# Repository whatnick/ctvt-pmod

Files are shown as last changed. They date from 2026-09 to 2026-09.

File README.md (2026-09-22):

# CTVT PMOD

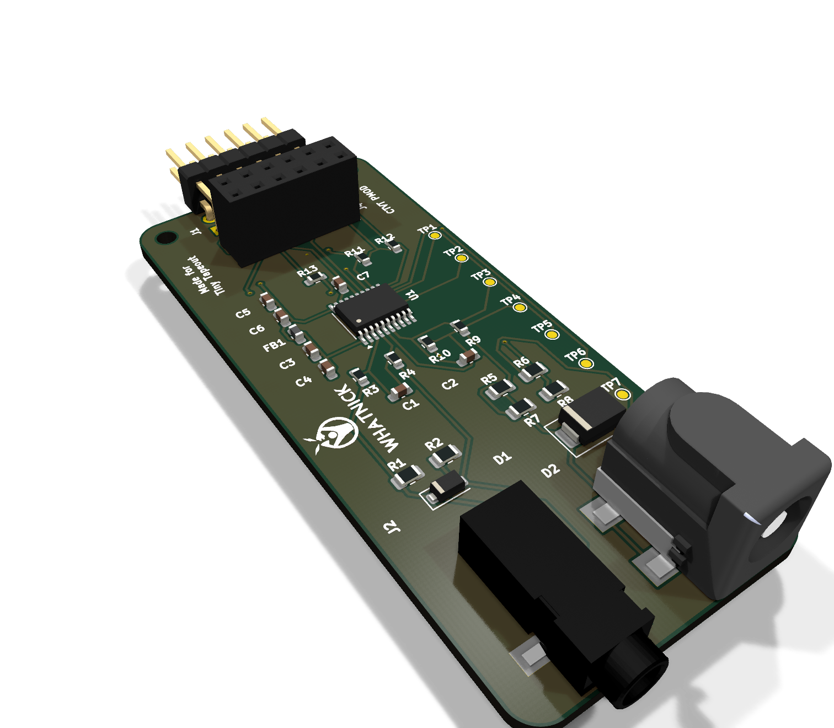
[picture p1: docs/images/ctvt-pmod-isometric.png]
CTVT PMOD assembled isometric render


CTVT PMOD is a compact, open-hardware analog front end for phase-coherent
current and voltage sampling. It uses a TI ADS131M02 dual 24-bit delta-sigma
ADC and is intended for energy-monitoring DSP experiments, including Tiny
Tapeout ASIC projects.

The routed KiCad 10 design is 30 mm x 70 mm with 3 mm corner radii and two
2.2 mm non-plated M2 mounting holes at the PMOD end. The PMOD connectors are
centered together on one short edge; the CT and AC/AC transformer inputs face
away from them at the opposite edge so adjacent PMODs remain usable. All
routed signals use 0.25 mm traces with 0.20 mm copper clearance.

The narrow layout keeps the measurement front end beside other PMODs rather
than blocking them. Both field connectors project beyond the board edge for
comfortable cable access, while the vertical female header provides a second
PMOD connection for stacking or logic-analyzer access.

| Component side | Rear silkscreen and routing |
|---|---|
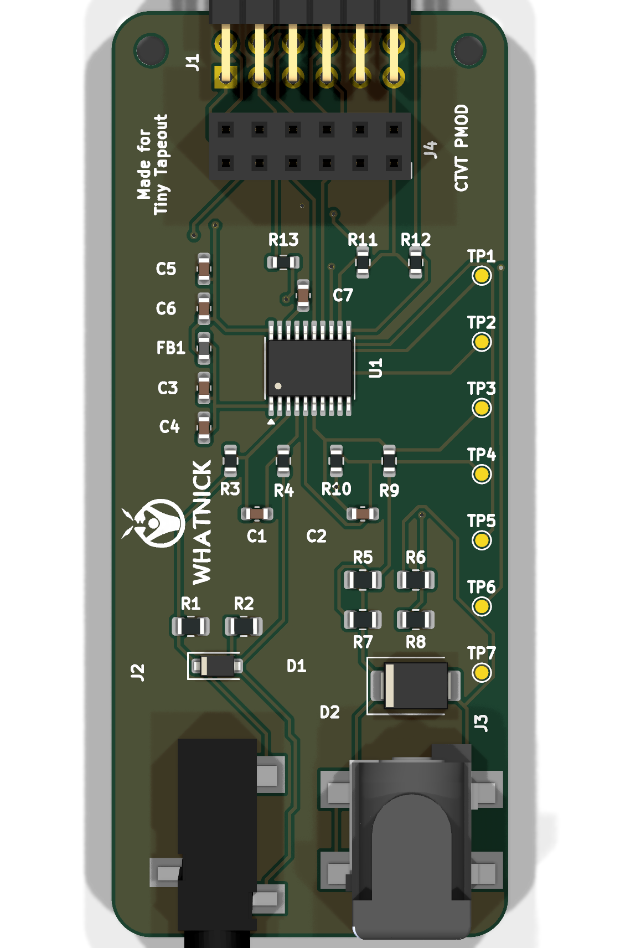
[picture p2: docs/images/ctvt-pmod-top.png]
Component-side render
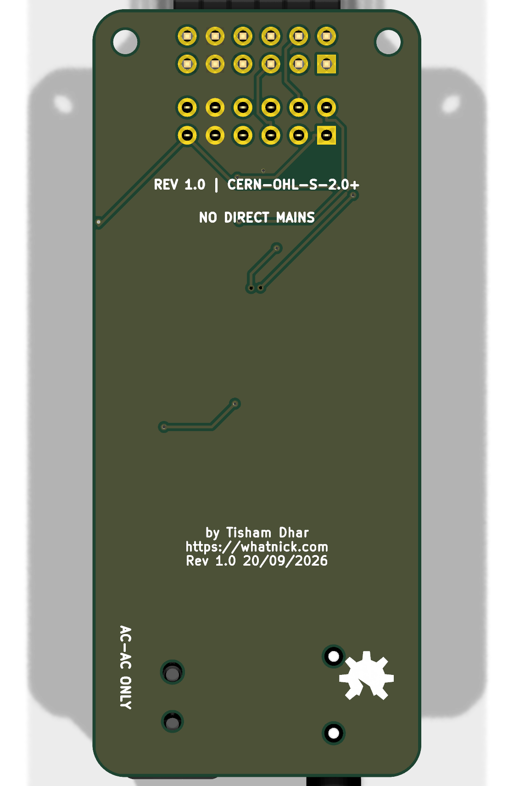
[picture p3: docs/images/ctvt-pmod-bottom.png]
Rear render
|  |  |

## Digital companion

The [CTVT Energy DSP](https://github.com/whatnick/tt-ctvt-energy-dsp)
repository contains the companion Tiny Tapeout design. Its working first stage
captures ADS131M02 frames, performs time-shared multiply-accumulate operations,
and publishes coherent voltage, current, and active-power moments over a host
SPI interface. The roadmap adds calibrated RMS and energy, phase/frequency,
power-quality events, and resource-efficient Goertzel harmonic analysis.

## Signal path

```text
CT jack -> split burden -> protection -> differential RC filter --+
                                                                   |
AC/AC jack -> balanced divider -> protection -> differential RC ---+-> ADS131M02
                                                                        |
3.3 V PMOD <---------------- SPI, DRDY, RESET, CLK ----------------------+
```

- **Current channel:** Same Sky `SJ-3523-SMT-TR` 3.5 mm stereo jack, with
  tip and sleeve as the differential CT input and ring grounded. Two 6.49 ohm
  0.1% burden resistors form a 12.98 ohm differential burden. The jack's
  mating face overhangs the field edge by 2.0 mm so a right-angle plug body
  clears the PCB.
- **Voltage channel:** Same Sky `PJ-002BH-SMT-TR` barrel jack for an isolated
  9-12 VAC transformer. Each leg uses a 100 kohm / 6.49 kohm balanced divider.
- **Filtering:** Each ADC channel has two 1 kohm series resistors and a 10 nF
  C0G differential capacitor, giving an approximate 8 kHz differential pole.
- **Assembly:** All chip passives are 0603 or larger and every fitted
  reference designator is present on silkscreen.
- **Protection:** `SMF3.3CA` on the CT input and `SMBJ18CA` on the transformer
  input.
- **Conversion:** ADS131M02 with filtered analog power, local decoupling,
  seven test points, and simultaneous voltage/current sampling.

## PMOD interface

J1 is the right-angle male peripheral connector. J4 is a vertical female
Wurth `613012243121` pass-through socket; all twelve pins are connected
one-to-one for PMOD chaining.

| Pin | Signal | Direction at CTVT | Purpose |
|---:|---|---|---|
| 1 | CS | Input | SPI chip select |
| 2 | MOSI | Input | SPI data to ADC |
| 3 | MISO | Output | SPI data from ADC |
| 4 | SCLK | Input | SPI clock |
| 5 | GND | Power | Ground |
| 6 | +3V3 | Power | Regulated 3.3 V input |
| 7 | DRDY | Output | Conversion-ready interrupt |
| 8 | RESET | Input | ADC reset |
| 9 | CLK_HOST | Input | Optional external ADC clock |
| 10 | RESERVED | Pass-through | Reserved chained signal |
| 11 | GND | Power | Ground |
| 12 | +3V3 | Power | Regulated 3.3 V input |

## Scaling and calibration

The CT channel differential voltage is:

```text
V_CT_RMS = I_secondary_RMS x 12.98 ohm
```

For example, a 100 A : 50 mA CT produces approximately 0.649 Vrms at rated
primary current. Confirm the selected CT's maximum secondary current and
fault behavior before connection.

The voltage channel nominal divider ratio is:

```text
6.49 kohm / (100 kohm + 6.49 kohm) = 0.06095
```

A 9-12 Vrms isolated transformer therefore produces approximately
0.549-0.731 Vrms differential at the ADC input. Configure the ADS131M02 gain
for the resulting peak voltage and retain headroom for transformer regulation
and mains excursions.

Calibrate voltage gain, current gain, phase, and channel offset against a
traceable low-voltage source before calculating power. TP1-TP4 expose the four
ADC inputs; TP5 is DRDY, TP6 is +3V3, and TP7 is GND.

## Safety

**Use only an isolated CT and a certified isolated AC/AC transformer. Never
connect mains directly to this board.** The barrel jack is an isolated
low-voltage AC input, not a DC supply input. Enclosure, wiring, fusing,
creepage, clearance, and regulatory compliance remain the responsibility of
the final system.

## Build and outputs

Open `ctvt-pmod.kicad_pro` in KiCad 10. The committed schematic and PCB are
complete and routed. Project-local connector footprints and STEP models avoid
dependencies on the ATM90E26 FeatherWing repository.

The design sources are generated in this order:

```powershell
python scripts\generate_schematic.py
& "C:\Program Files\KiCad\10.0\bin\python.exe" scripts\generate_board.py
# Export a Specctra DSN, route it, and save the result as routing\ctvt-pmod.ses.
& "C:\Program Files\KiCad\10.0\bin\python.exe" scripts\finalize_route.py
```

`scripts/finalize_route.py` imports the saved Freerouting session, normalizes
all traces to at least 0.25 mm, verifies the stereo jack's generated 2.0 mm
mating-face overhang, adds the rear OSHW/Whatnick branding, and fills GND zones
on both copper layers. Run `scripts\adjust_stereo_jack.py` to verify the
overhang independently or
`scripts\add_branding.py` to reapply only the branding.
Run `scripts\add_mechanical_features.py` to reapply the 3 mm corner radii and
two M2 mounting holes without disturbing routed copper or manual silkscreen.
Manufacturing exports are generated into ignored `gerbers/` and `bom/`
directories. The reviewed orderable BOM and DigiKey sourcing notes are
committed in [`docs/ctvt-pmod-sourced-bom.csv`](docs/ctvt-pmod-sourced-bom.csv)
and [`docs/bom-sourcing.md`](docs/bom-sourcing.md).

## Repository contents

- `ctvt-pmod.kicad_sch` - complete schematic
- `ctvt-pmod.kicad_pcb` - routed two-layer PCB
- `ctvt-pmod.pretty/` - project-local barrel-jack and PMOD socket footprints
- `models/step/` - project-local connector STEP models
- `routing/ctvt-pmod.ses` - saved autorouter result
- `scripts/` - deterministic schematic, placement, and routing finalization

Licensed under CERN-OHL-S-2.0-or-later.

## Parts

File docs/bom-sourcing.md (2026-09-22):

# DigiKey BOM sourcing

The orderable BOM is in
[`ctvt-pmod-sourced-bom.csv`](ctvt-pmod-sourced-bom.csv). DigiKey parts were
checked through the Product Search API on 2026-09-22 using the Australian
locale, with in-stock and RoHS-compliant filters.

The selected parts preserve the schematic values and PCB footprints. In
particular, the 10 nF C0G capacitors use 0603 `GRM188` parts and the ferrite
bead uses a 0603 `MPZ1608` part; the earlier `GRM155` and `BLM15` MPNs were
0402 parts and did not match the board footprints.

R1 and R2 use TE Connectivity Holsworthy `RN73C2A6R49BTDF`, sourced from
[Mouser Australia](https://au.mouser.com/en/ProductDetail/TE-Connectivity-Holsworthy/RN73C2A6R49BTDF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).
It is a footprint-compatible 6.49 ohm, 0.1%, 0805 thin-film resistor with a
10 ppm/degree C temperature coefficient and a 0.1 W rating.

Stock and pricing change continuously. Recheck all DigiKey part numbers before
ordering, especially the ADC, connectors, D1, C7, and the precision resistors.

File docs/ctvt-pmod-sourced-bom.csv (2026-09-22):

References | Quantity | Value | Manufacturer | Manufacturer Part Number | Supplier | Supplier Part Number | Package | Sourcing Note
C1 C2 | 2 | 10nF C0G | Murata Electronics | GRM1885C1H103JA01D | DigiKey | 490-9666-1-ND | 0603 | 50 V C0G 5%
C3 C5 | 2 | 1uF | KEMET | C0603C105K4RACTU | DigiKey | 399-C0603C105K4RACTUCT-ND | 0603 | 16 V X7R 10%
C4 C6 | 2 | 100nF | KEMET | C0603C104K5RACTU | DigiKey | 399-C0603C104K5RACTUCT-ND | 0603 | 50 V X7R 10%
C7 | 1 | 220nF | KEMET | C0603C224K4RACTU | DigiKey | 399-C0603C224K4RACTUCT-ND | 0603 | 16 V X7R 10%
D1 | 1 | SMF3.3CA | Good-Ark Semiconductor | GSMF3.3CA | DigiKey | 4786-GSMF3.3CACT-ND | SOD-123F | 3.3 V bidirectional TVS
D2 | 1 | SMBJ18CA | Littelfuse | SMBJ18CA | DigiKey | SMBJ18CALFCT-ND | DO-214AA SMB | 18 V bidirectional TVS
FB1 | 1 | 600R@100MHz | TDK | MPZ1608S601ATA00 | DigiKey | 445-MPZ1608S601ATA00CT-ND | 0603 | 600 ohm at 100 MHz
J1 | 1 | Tiny Tapeout PMOD | Samtec | TSW-106-08-G-D-RA | DigiKey | 612-TSW-106-08-G-D-RA-ND | 2x6 2.54 mm THT | Right-angle male header
J2 | 1 | SJ-3523-SMT-TR | Same Sky | SJ-3523-SMT-TR | DigiKey | CP-3523SJCT-ND | SMD | 3.5 mm stereo jack
J3 | 1 | PJ-002BH-SMT-TR | Same Sky | PJ-002BH-SMT-TR | DigiKey | CP-002BHPJCT-ND | SMD | 2.5 x 5.5 mm barrel jack
J4 | 1 | 613012243121 | Wurth Elektronik | 613012243121 | DigiKey | 732-613012243121-ND | 2x6 2.54 mm THT | Vertical female socket
R1 R2 | 2 | 6.49R 0.1% | TE Connectivity Holsworthy | RN73C2A6R49BTDF | Mouser | RN73C2A6R49BTDF | 0805 | 10 ppm/C thin film
R3 R4 R9 R10 | 4 | 1k 0.1% | Susumu | RG1608P-102-B-T5 | DigiKey | RG16P1.0KBCT-ND | 0603 | 25 ppm/C thin film
R5 R6 | 2 | 100k 0.1% | Panasonic Industry | ERA-6AEB104V | DigiKey | P100KDACT-ND | 0805 | 25 ppm/C thin film
R7 R8 | 2 | 6.49k 0.1% | Yageo | RT0805BRD076K49L | DigiKey | YAG1965CT-ND | 0805 | 25 ppm/C thin film
R11 R12 | 2 | 10k 1% | Stackpole Electronics | RMCF0603FT10K0 | DigiKey | RMCF0603FT10K0CT-ND | 0603 | General-purpose
R13 | 1 | 33R 1% | Yageo | RC0603FR-0733RL | DigiKey | 13-RC0603FR-0733RLCT-ND | 0603 | General-purpose
U1 | 1 | ADS131M02IPWR | Texas Instruments | ADS131M02IPWR | DigiKey | 296-ADS131M02IPWRCT-ND | TSSOP-20 | 24-bit dual-channel ADC

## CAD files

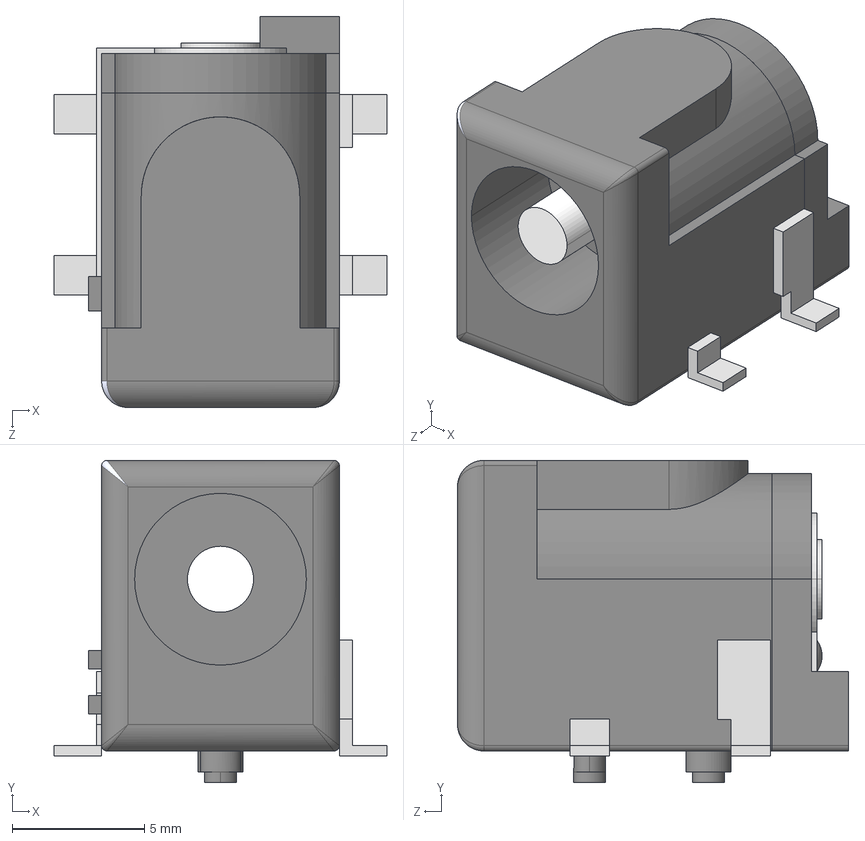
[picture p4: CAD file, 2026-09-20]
models/step/CUI_PJ-002BH-SMT-TR.step
12.6 x 12.2 x 14.8 mm

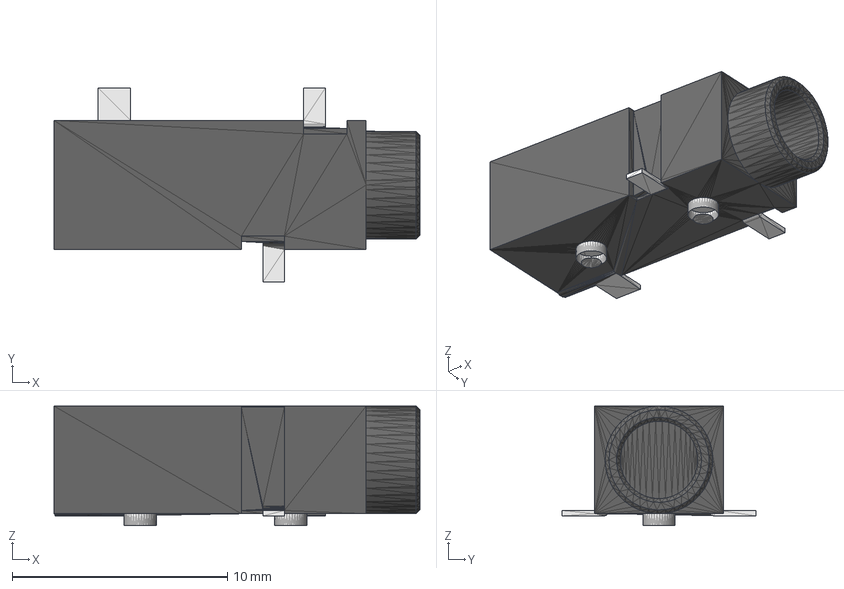
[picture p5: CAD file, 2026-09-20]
models/step/CUI_SJ-3523.step
17.0 x 9.00 x 5.80 mm

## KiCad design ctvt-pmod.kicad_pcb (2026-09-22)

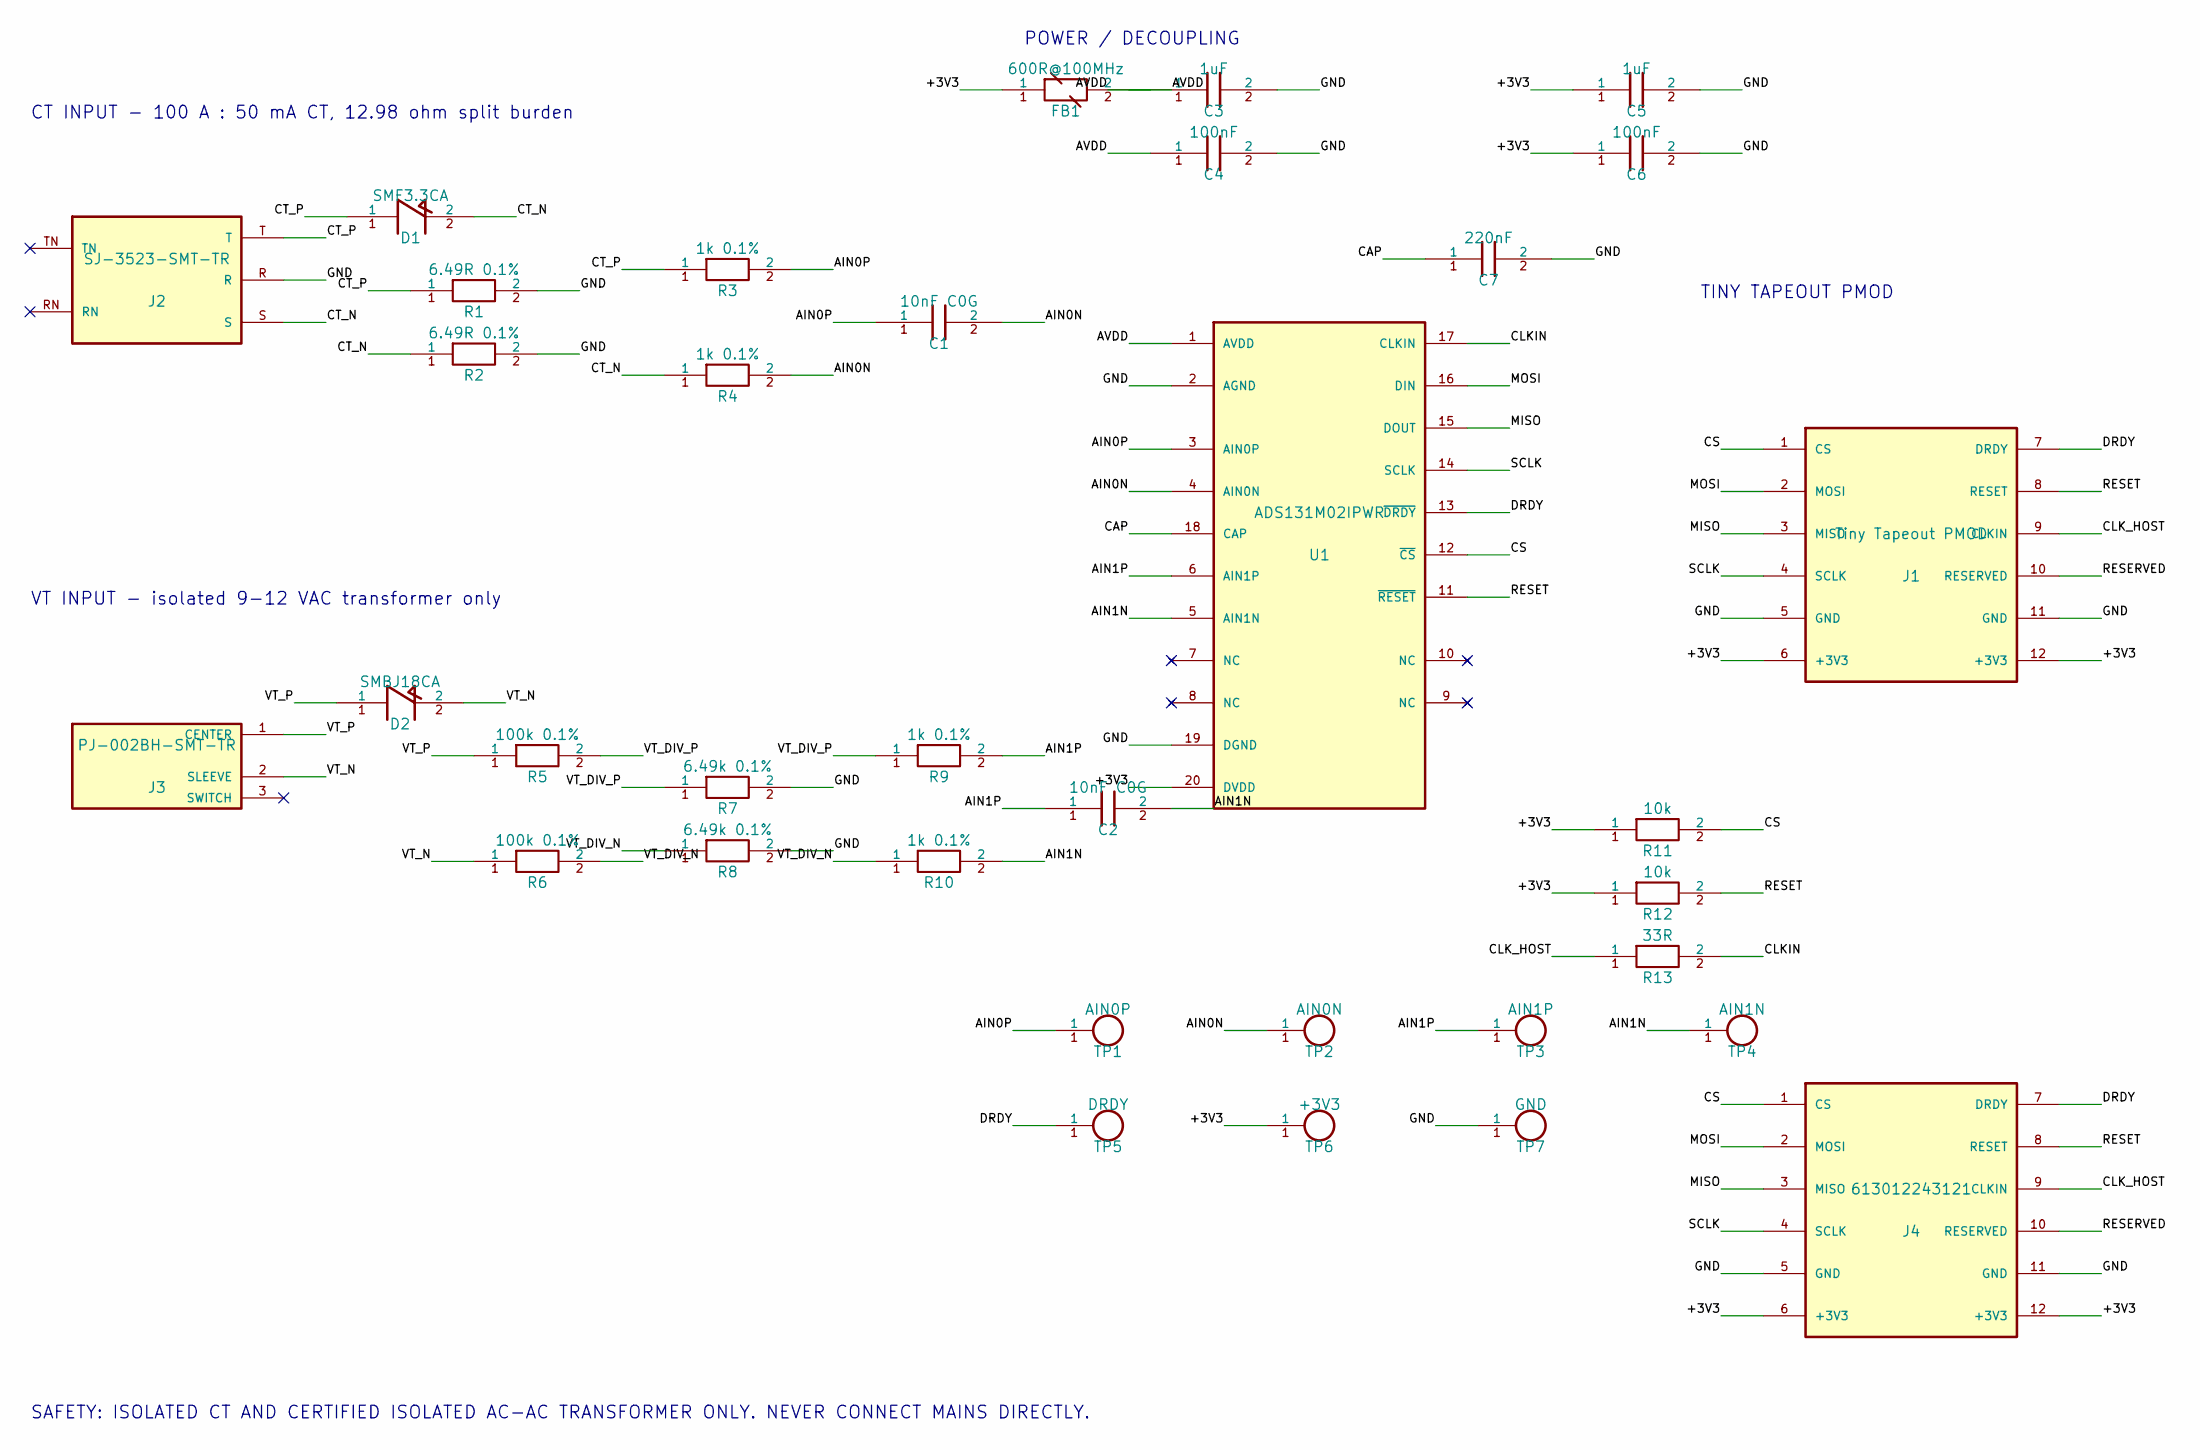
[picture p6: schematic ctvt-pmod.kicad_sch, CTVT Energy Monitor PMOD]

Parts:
C1, C2: 10nF C0G; C_0603_1608Metric; MPN GRM1555C1H103JA01D
C3, C5: 1uF; C_0603_1608Metric
C4, C6: 100nF; C_0603_1608Metric
C7: 220nF; C_0603_1608Metric
D1: SMF3.3CA; D_SOD-123F
D2: SMBJ18CA; D_SMB
FB1: 600R@100MHz; L_0603_1608Metric; MPN BLM15AG601SN1D
J1: Tiny Tapeout PMOD; PinHeader_2x06_P2.54mm_Horizontal
J2: SJ-3523-SMT-TR; Jack_3.5mm_CUI_SJ-3523-SMT_Horizontal; MPN SJ-3523-SMT-TR
J3: PJ-002BH-SMT-TR; DC_BARREL_JACK_SMD_2MM; MPN PJ-002BH-SMT-TR
J4: 613012243121; PinSocket_2x06_P2.54mm_PMODHost1A; MPN 613012243121
R1, R2: 6.49R 0.1%; R_0805_2012Metric; MPN TNPW08056R49BEEA
R3, R4, R9, R10: 1k 0.1%; R_0603_1608Metric
R5, R6: 100k 0.1%; R_0805_2012Metric
R7, R8: 6.49k 0.1%; R_0805_2012Metric
R11, R12: 10k; R_0603_1608Metric
R13: 33R; R_0603_1608Metric
TP1: AIN0P; TestPoint_Pad_D1.0mm
TP2: AIN0N; TestPoint_Pad_D1.0mm
TP3: AIN1P; TestPoint_Pad_D1.0mm
TP4: AIN1N; TestPoint_Pad_D1.0mm
TP5: DRDY; TestPoint_Pad_D1.0mm
TP6: +3V3; TestPoint_Pad_D1.0mm
TP7: GND; TestPoint_Pad_D1.0mm
U1: ADS131M02IPWR; TSSOP-20_4.4x6.5mm_P0.65mm; MPN ADS131M02IPWR

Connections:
+3V3: C5.1, C6.1, FB1.1, J1.6 (+3V3), J1.12 (+3V3), J4.6 (+3V3), J4.12 (+3V3), R11.1, R12.1, TP6.1, U1.20 (DVDD)
AIN0N: C1.2, R4.2, TP2.1, U1.4 (AIN0N)
AIN0P: C1.1, R3.2, TP1.1, U1.3 (AIN0P)
AIN1N: C2.2, R10.2, TP4.1, U1.5 (AIN1N)
AIN1P: C2.1, R9.2, TP3.1, U1.6 (AIN1P)
AVDD: C3.1, C4.1, FB1.2, U1.1 (AVDD)
CAP: C7.1, U1.18 (CAP)
CLKIN: R13.2, U1.17 (CLKIN)
CLK_HOST: J1.9 (CLKIN), J4.9 (CLKIN), R13.1
CS: J1.1 (CS), J4.1 (CS), R11.2, U1.12 (~CS)
CT_N: D1.2, J2.S, R2.1, R4.1
CT_P: D1.1, J2.T, R1.1, R3.1
DRDY: J1.7 (DRDY), J4.7 (DRDY), TP5.1, U1.13 (~DRDY)
GND: C3.2, C4.2, C5.2, C6.2, C7.2, J1.5 (GND), J1.11 (GND), J2.R, J4.5 (GND), J4.11 (GND), R1.2, R2.2, R7.2, R8.2, TP7.1, U1.2 (AGND), U1.19 (DGND)
MISO: J1.3 (MISO), J4.3 (MISO), U1.15 (DOUT)
MOSI: J1.2 (MOSI), J4.2 (MOSI), U1.16 (DIN)
RESERVED: J1.10 (RESERVED), J4.10 (RESERVED)
RESET: J1.8 (RESET), J4.8 (RESET), R12.2, U1.11 (~RESET)
SCLK: J1.4 (SCLK), J4.4 (SCLK), U1.14 (SCLK)
VT_DIV_N: R6.2, R8.1, R10.1
VT_DIV_P: R5.2, R7.1, R9.1
VT_N: D2.2, J3.2 (SLEEVE), R6.1
VT_P: D2.1, J3.1 (CENTER), R5.1

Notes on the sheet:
CT INPUT - 100 A : 50 mA CT, 12.98 ohm split burden
VT INPUT - isolated 9-12 VAC transformer only
POWER / DECOUPLING
TINY TAPEOUT PMOD
SAFETY: ISOLATED CT AND CERTIFIED ISOLATED AC-AC TRANSFORMER ONLY. NEVER CONNECT MAINS DIRECTLY.

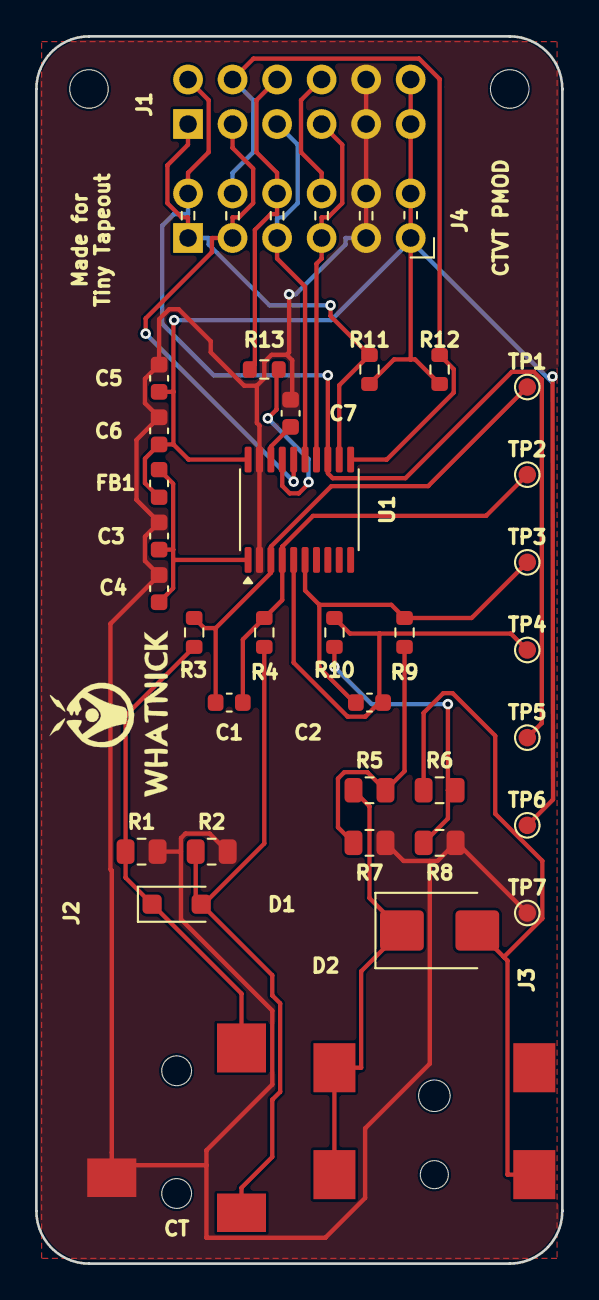
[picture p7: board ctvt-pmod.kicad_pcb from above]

Board: 2 copper layers, 30.0 x 70.0 mm, 39 parts (1 on the bottom side), 23 nets.

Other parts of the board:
H1, H2: M2 mounting hole; MountingHole_2.2mm_M2
LOGO1: OSHW-LOGO-M
LOGO2: Whatnick_logo

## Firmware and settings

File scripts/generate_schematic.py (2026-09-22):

from __future__ import annotations

import shutil
import subprocess
import tempfile
from dataclasses import dataclass, field
from pathlib import Path


ROOT = Path(__file__).resolve().parents[1]
OUTPUT = ROOT / "ctvt-pmod.kicad_sch"
SYMBOL_LIBRARY_OUTPUT = ROOT / "ctvt-pmod-cache.kicad_sym"
SYMBOL_TABLE_OUTPUT = ROOT / "sym-lib-table"
KICAD_CLI = Path(r"C:\Program Files\KiCad\10.0\bin\kicad-cli.exe")
KICAD_REVIVE = (
    "git+https://github.com/mgyenik/kicad-revive.git"
    "@2847877af4a3114fd1e61ab2f660089fa3c27ecc"
)


CUSTOM_LIBRARY = r"""EESchema-LIBRARY Version 2.4
#encoding utf-8
#
# ADS131M02PW
#
DEF ADS131M02PW U 0 40 Y Y 1 F N
F0 "U" 0 1150 50 H V C CNN
F1 "ADS131M02PW" 0 1050 50 H V C CNN
F2 "" 0 0 50 H I C CNN
F3 "" 0 0 50 H I C CNN
DRAW
S -500 1000 500 -1300 0 1 12 f
X AVDD 1 -700 900 200 R 40 40 1 1 W
X ~RESET 11 700 -300 200 L 40 40 1 1 I
X ~CS 12 700 -100 200 L 40 40 1 1 I
X ~DRDY 13 700 100 200 L 40 40 1 1 O
X SCLK 14 700 300 200 L 40 40 1 1 I
X DOUT 15 700 500 200 L 40 40 1 1 O
X DIN 16 700 700 200 L 40 40 1 1 I
X CLKIN 17 700 900 200 L 40 40 1 1 I
X CAP 18 -700 0 200 R 40 40 1 1 w
X DGND 19 -700 -1000 200 R 40 40 1 1 W
X AGND 2 -700 700 200 R 40 40 1 1 W
X DVDD 20 -700 -1200 200 R 40 40 1 1 W
X AIN0P 3 -700 400 200 R 40 40 1 1 I
X AIN0N 4 -700 200 200 R 40 40 1 1 I
X AIN1N 5 -700 -400 200 R 40 40 1 1 I
X AIN1P 6 -700 -200 200 R 40 40 1 1 I
X NC 7 -700 -600 200 R 40 40 1 1 N
X NC 8 -700 -800 200 R 40 40 1 1 N
X NC 9 700 -800 200 L 40 40 1 1 N
X NC 10 700 -600 200 L 40 40 1 1 N
ENDDRAW
ENDDEF
#
# R
#
DEF R R 0 0 Y Y 1 F N
F0 "R" 0 80 50 H V C CNN
F1 "R" 0 0 50 H V C CNN
F2 "" 0 0 50 H I C CNN
F3 "" 0 0 50 H I C CNN
DRAW
S -100 50 100 -50 0 1 10 N
X 1 1 -300 0 200 R 40 40 1 1 P
X 2 2 300 0 200 L 40 40 1 1 P
ENDDRAW
ENDDEF
#
# C
#
DEF C C 0 0 Y Y 1 F N
F0 "C" 0 90 50 H V C CNN
F1 "C" 0 -90 50 H V C CNN
F2 "" 0 0 50 H I C CNN
F3 "" 0 0 50 H I C CNN
DRAW
P 2 0 1 12 -30 80 -30 -80 N
P 2 0 1 12 30 80 30 -80 N
X 1 1 -300 0 270 R 40 40 1 1 P
X 2 2 300 0 270 L 40 40 1 1 P
ENDDRAW
ENDDEF
#
# FB
#
DEF FB FB 0 0 Y Y 1 F N
F0 "FB" 0 90 50 H V C CNN
F1 "Ferrite" 0 -90 50 H V C CNN
F2 "" 0 0 50 H I C CNN
F3 "" 0 0 50 H I C CNN
DRAW
S -100 50 100 -50 0 1 10 N
P 2 0 1 10 -70 80 -20 30 N
P 2 0 1 10 20 -30 70 -80 N
X 1 1 -300 0 200 R 40 40 1 1 P
X 2 2 300 0 200 L 40 40 1 1 w
ENDDRAW
ENDDEF
#
# TVS
#
DEF TVS D 0 0 Y Y 1 F N
F0 "D" 0 100 50 H V C CNN
F1 "TVS" 0 -100 50 H V C CNN
F2 "" 0 0 50 H I C CNN
F3 "" 0 0 50 H I C CNN
DRAW
P 3 0 1 12 -60 -80 -60 80 70 0 N
P 4 0 1 12 70 -80 70 80 40 50 100 20 N
X 1 1 -300 0 240 R 40 40 1 1 P
X 2 2 300 0 230 L 40 40 1 1 P
ENDDRAW
ENDDEF
#
# AUDIO_JACK
#
DEF AUDIO_JACK J 0 40 Y Y 1 F N
F0 "J" 0 450 50 H V C CNN
F1 "CT stereo jack" 0 350 50 H V C CNN
F2 "" 0 0 50 H I C CNN
F3 "" 0 0 50 H I C CNN
DRAW
S -400 300 400 -300 0 1 12 f
X T T 600 200 200 L 40 40 1 1 P
X R R 600 0 200 L 40 40 1 1 P
X S S 600 -200 200 L 40 40 1 1 P
X TN TN -600 150 200 R 40 40 1 1 P
X RN RN -600 -150 200 R 40 40 1 1 P
ENDDRAW
ENDDEF
#
# BARREL_JACK
#
DEF BARREL_JACK J 0 40 Y Y 1 F N
F0 "J" 0 350 50 H V C CNN
F1 "AC-AC barrel jack" 0 250 50 H V C CNN
F2 "" 0 0 50 H I C CNN
F3 "" 0 0 50 H I C CNN
DRAW
S -400 200 400 -200 0 1 12 f
X CENTER 1 600 150 200 L 40 40 1 1 P
X SLEEVE 2 600 -50 200 L 40 40 1 1 P
X SWITCH 3 600 -150 200 L 40 40 1 1 P
ENDDRAW
ENDDEF
#
# PMOD
#
DEF PMOD J 0 40 Y Y 1 F N
F0 "J" 0 750 50 H V C CNN
F1 "Tiny Tapeout PMOD" 0 650 50 H V C CNN
F2 "" 0 0 50 H I C CNN
F3 "" 0 0 50 H I C CNN
DRAW
S -500 600 500 -600 0 1 12 f
X CS 1 -700 500 200 R 40 40 1 1 B
X MOSI 2 -700 300 200 R 40 40 1 1 B
X MISO 3 -700 100 200 R 40 40 1 1 B
X SCLK 4 -700 -100 200 R 40 40 1 1 B
X GND 5 -700 -300 200 R 40 40 1 1 w
X +3V3 6 -700 -500 200 R 40 40 1 1 w
X DRDY 7 700 500 200 L 40 40 1 1 B
X RESET 8 700 300 200 L 40 40 1 1 B
X CLKIN 9 700 100 200 L 40 40 1 1 B
X RESERVED 10 700 -100 200 L 40 40 1 1 B
X GND 11 700 -300 200 L 40 40 1 1 P
X +3V3 12 700 -500 200 L 40 40 1 1 P
ENDDRAW
ENDDEF
#
# PMOD_PASSIVE
#
DEF PMOD_PASSIVE J 0 40 Y Y 1 F N
F0 "J" 0 750 50 H V C CNN
F1 "PMOD pass-through" 0 650 50 H V C CNN
F2 "" 0 0 50 H I C CNN
F3 "" 0 0 50 H I C CNN
DRAW
S -500 600 500 -600 0 1 12 f
X CS 1 -700 500 200 R 40 40 1 1 P
X MOSI 2 -700 300 200 R 40 40 1 1 P
X MISO 3 -700 100 200 R 40 40 1 1 P
X SCLK 4 -700 -100 200 R 40 40 1 1 P
X GND 5 -700 -300 200 R 40 40 1 1 P
X +3V3 6 -700 -500 200 R 40 40 1 1 P
X DRDY 7 700 500 200 L 40 40 1 1 P
X RESET 8 700 300 200 L 40 40 1 1 P
X CLKIN 9 700 100 200 L 40 40 1 1 P
X RESERVED 10 700 -100 200 L 40 40 1 1 P
X GND 11 700 -300 200 L 40 40 1 1 P
X +3V3 12 700 -500 200 L 40 40 1 1 P
ENDDRAW
ENDDEF
#
# TP
#
DEF TP TP 0 0 Y Y 1 F N
F0 "TP" 0 180 50 H V C CNN
F1 "Test point" 0 80 50 H V C CNN
F2 "" 0 0 50 H I C CNN
F3 "" 0 0 50 H I C CNN
DRAW
C 0 0 70 0 1 12 N
X 1 1 -250 0 180 R 40 40 1 1 P
ENDDRAW
ENDDEF
#
#End Library
"""


@dataclass
class Component:
    symbol: str
    ref: str
    value: str
    footprint: str
    x: int
    y: int
    fields: dict[str, str] = field(default_factory=dict)


def component_block(component: Component, timestamp: int) -> str:
    fields = [
        f'F 0 "{component.ref}" H {component.x} {component.y - 100} 50  0000 C CNN',
        f'F 1 "{component.value}" H {component.x} {component.y + 100} 50  0000 C CNN',
        f'F 2 "{component.footprint}" H {component.x} {component.y} 50  0001 C CNN',
        f'F 3 "" H {component.x} {component.y} 50  0001 C CNN',
    ]
    for index, (name, value) in enumerate(component.fields.items(), start=4):
        fields.append(
            f'F {index} "{value}" H {component.x} {component.y} 50  0001 C CNN "{name}"'
        )
    return "\n".join(
        [
            "$Comp",
            f"L ctvt-pmod-cache:{component.symbol} {component.ref}",
            f"U 1 1 {timestamp:08X}",
            f"P {component.x} {component.y}",
            *fields,
            f"\t1    {component.x} {component.y}",
            "\t1    0    0    -1",
            "$EndComp",
        ]
    )


def wire_label(x: int, y: int, net: str, direction: int = 1) -> str:
    end_x = x + direction * 200
    justify = 0 if direction > 0 else 2
    return "\n".join(
        [
            f"Wire Wire Line",
            f"\t{x} {y} {end_x} {y}",
            f"Text Label {end_x} {y} {justify}    40   ~ 0",
            net,
        ]
    )


def no_connect(x: int, y: int) -> str:
    return f"NoConn ~ {x} {y}"


def note(x: int, y: int, text: str) -> str:
    return f'Text Notes {x} {y} 0    60   ~ 12\n{text}'
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

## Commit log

2026-08-14 Create CTVT PMOD placeholder design
    Add an independent KiCad 10 project defining the initial ADS131M02-based CT and VT energy-monitor architecture.
    [ctvt-pmod.kicad_pcb, ctvt-pmod.kicad_sch]
2026-09-20 Complete routed CTVT energy monitor PMOD
    Implement the ADS131M02 CT/VT analog front end, exact field connectors, chained PMOD interface, reproducible routing and branded fabrication-ready layout. Add architecture, calibration, safety docume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
    [CUI_PJ-002BH-SMT-TR.step, CUI_SJ-3523.step, ctvt-pmod.kicad_pcb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]
2026-09-20 Capture final silkscreen hierarchy
    Preserve the manual 0.8 mm/0.2 mm silkscreen normalization, aligned references, front-side Whatnick and Tiny Tapeout identity, and rear safety/legal markings in the generators. Refresh README renders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
    [ctvt-pmod.kicad_pcb]
2026-09-22 Round board corners and add mounting holes
    Apply 3 mm radii to the 30 x 70 mm outline and add two accessible M2 NPTH mounting holes at the PMOD end without disturbing the connector edge. Preserve the mechanical update in the board generator a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
    [ctvt-pmod.kicad_pcb]
2026-09-22 Widen all routed traces
    Reroute the unchanged CTVT PMOD placement at a uniform 0.25 mm trace width with 0.20 mm clearance. Persist the wider default in KiCad settings and generators, replace the Freerouting session, reduce the route from 29 to 11 vias, and refresh all board renders.
    [ctvt-pmod.kicad_pcb]
2026-09-22 Center both PMOD connectors
    [ctvt-pmod.kicad_pcb]
2026-09-22 Add sourced DigiKey bill of materials
    [ctvt-pmod-digikey-bom.csv, ctvt-pmod.kicad_sch]
2026-09-22 Use TE precision burden resistors
    [ctvt-pmod-digikey-bom.csv, ctvt-pmod-sourced-bom.csv, ctvt-pmod.kicad_sch]
2026-10-12 Prepare Elecrow PCBA manufacturing package
    Correct J4 to the vertical Wurth 61301221821 socket, add deterministic KiCad 10 manufacturing exports, and include verified Gerber, BOM, position, and combined Elecrow upload archives.
2026-10-16 Document ADC PMOD competitive landscape
    Compare the CTVT phase-coherent metrology front end with 17 commercial ADC and mixed-signal PMOD boards, including architecture, isolation, pricing, and positioning tradeoffs.

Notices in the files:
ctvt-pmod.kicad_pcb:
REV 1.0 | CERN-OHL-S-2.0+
